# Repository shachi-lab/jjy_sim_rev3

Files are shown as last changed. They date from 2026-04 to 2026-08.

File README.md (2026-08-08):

# 📡 JJY Simulator Rev.3 for ESP32-C3 / ESP8684

Build your own JJY time-signal simulator with an ESP32-C3 or ESP8684!  
This compact simulator reproduces the 40 kHz / 60 kHz JJY radio time signal using PWM output,  
based on accurate time obtained from NTP.  
Rev.3 is developed with ESP-IDF.  

Latest version: **R3-1.0.6**

👉 [README 日本語版はこちら](README_ja.md)

---

## 🪛 Features

* Supports both **ESP32-C3** and **ESP8684**
* Full-featured implementation based on **ESP-IDF**
* **Easy AP mode** for Wi-Fi setup with a single button
* **OLED display** for checking the current time and sync status
* Automatic time synchronization via **NTP**
* Switchable **JJY 40 kHz (eastern Japan) / 60 kHz (western Japan)**
* Output **band optimization** can be selected with an on-board switch
* Signal is radiated from a built-in **simple antenna** on the board
* **H-bridge output stage** for higher output power (may transmit farther than expected)
* Configuration page accessible from a **web browser**
* Supports **time zones** and **DST (Daylight Saving Time)**
* **Hourly Mode** for periodic JJY signal output
* **Night Mode** for reducing OLED display brightness at night
* **Offset Time** adjustment for fine-tuning the transmitted time
* Displays a **clock screen** during operation

<a href="./images/jjy-sim-r3.jpg">
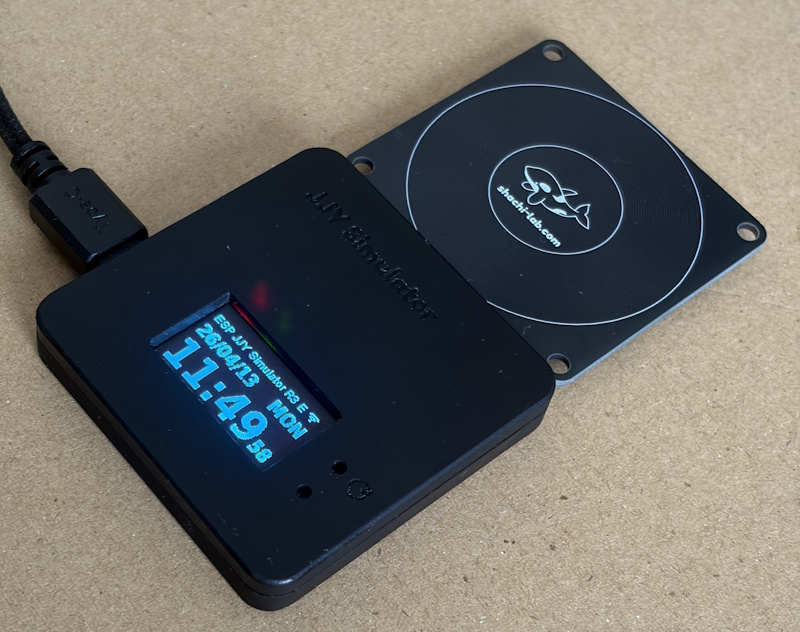
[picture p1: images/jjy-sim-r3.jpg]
JJY Simulator Rev.3
</a><br/>

---

## 🛠 Build and Flash (ESP-IDF / CLI)

JJY-SIM R3 is built and flashed using ESP-IDF.  
R2 was Arduino-based,  
but R3 has moved to ESP-IDF for better timing accuracy and a cleaner overall architecture.

> ### ⚠️ Note
> * This project cannot be built in the Arduino environment
> * This is an ESP-IDF-only project

### ■ Environment

* ESP-IDF v5.x
* Python (with a working `idf.py` environment)

For ESP-IDF setup, please refer to the official documentation.

### ■ Build

Move to the project directory and run:

```bash
idf.py build
```

### ■ Flash

```bash
idf.py flash
```

If you need to specify the serial port:

```bash
idf.py -p COMx flash
```

### ■ Serial Monitor

```bash
idf.py monitor
```

### ■ Full Command

```bash
idf.py -p COMx flash monitor
```

This single command lets you flash the firmware and open the log output at the same time.

### ■ Target Selection

Set the target once during initial setup.
The required target depends on which module you are using.

* When using **ESP32-C3**:

```bash
idf.py set-target esp32c3
```

* When using **ESP8684**:
  Since the ESP8684 is based on **ESP32-C2**,
  select `esp32c2` as the chip target.

```bash
idf.py set-target esp32c2
```

---

## 🛠 Build and Flash (VSCode / GUI)

You can also develop this project using **VSCode + the ESP-IDF Extension**.

### ■ Recommended Extension

* ESP-IDF Extension (Espressif)

By installing the extension in VSCode, you can perform the following from the GUI:

* Build
* Flash
* Serial monitor

### ■ Setup

Set up your environment according to the ESP-IDF Extension instructions.

Once the extension is installed, you can run actions such as:

* `Build`
* `Flash`
* `Monitor`

with a single click.

### ■ Workspace

When opening the project in VSCode,
open **`jjy-sim-r3.code-workspace`** in the source-code folder
to work with the ESP-IDF Extension settings already included.

---

## ⚙️ Usage

### ■ Wi-Fi Setup

* After power-on or reset, press the **CONFIG** switch within 5 seconds  
  On first boot, the device enters Wi-Fi setup mode automatically
* An AP named `JJY-SIM-R3-XXXXXXXX` will start
* Connect from a smartphone or PC → a captive portal will appear
* Select the SSID and enter the password
* You can also configure the band, local time, and DST (Daylight Saving Time) as needed
* Click **[Save and Reboot]** to save the settings and restart the device

### ■ Operation Check

* After power-on or reset, the logo is shown. If left untouched for 5 seconds, the device will try to connect to the configured Wi-Fi AP
* Once connected, it obtains the current time from an NTP server
* The current time is shown on the OLED, and JJY signal output starts from second 0 using PWM
* Just press the **receive button** on your radio-controlled clock and place it nearby

### ■ Controls During Operation

While the clock screen is displayed, the following operations are available:

* Press the **[CONFIG]** button for about 1 second to show the information screen  
  Press **[CONFIG]** again to return to the clock screen
* Press and hold the **[CONFIG]** button for 5 seconds or longer to stop JJY transmission output  
  Press and hold **[CONFIG]** again for 5 seconds or longer to resume JJY transmission output

---

## 🔌 Pin Assignment (Main Signals)

| Function | GPIO | Notes |
| --- | ---- | --- |
| JJY PWM output | 10,4 | Modulated output signals, inverted A/B pair for the H-bridge |
| CONFIG switch  | 9 | Used for Wi-Fi setup (**shared with BOOT pin**) |
| ACT LED | 5 | Activity LED |
| IND LED | 0 | Status indicator LED (can be shared) |
| OLED Reset | 2 | OLED module reset |
| OLED SDA | 7 | OLED I2C data |
| OLED SCL | 6 | OLED I2C clock |

---

## 🧾 File Structure

### 💻 Firmware

* The firmware source code is located in the **`firmware/idf`** folder.
* This firmware uses a rebuilt library, ported as an IDF component, based on the Arduino OLED driver library used in R2.  
This component is publicly available on GitHub.  
👉 [SSD1306 OLED display driver](https://github.com/Shachi-lab/oled_display)
* `storage_key.h` contains placeholder values and can be used as-is.  
  For better security, you may want to replace them with your own values before building.

### 🧰 Hardware

* The hardware design files are located in the **`hardware`** folder.
* The schematic and PCB design data are in **`hardware/KiCad`**.

  * Compatible with **KiCad Ver.9** only (cannot be opened with Ver.8 or earlier)
  * **Gerber data** is included in **`KiCad/PLOT`**, so the board can be fabricated as-is
* The 3D case data is in **`hardware/case_3d`**.

---

## 📸 Appearance / Assembly Examples

These are the board and case exterior views.  
The design uses a black PCB and a black case so that only the display appears to float visually.

<a href="./images/jjy-sim-r3_pcb.jpg">
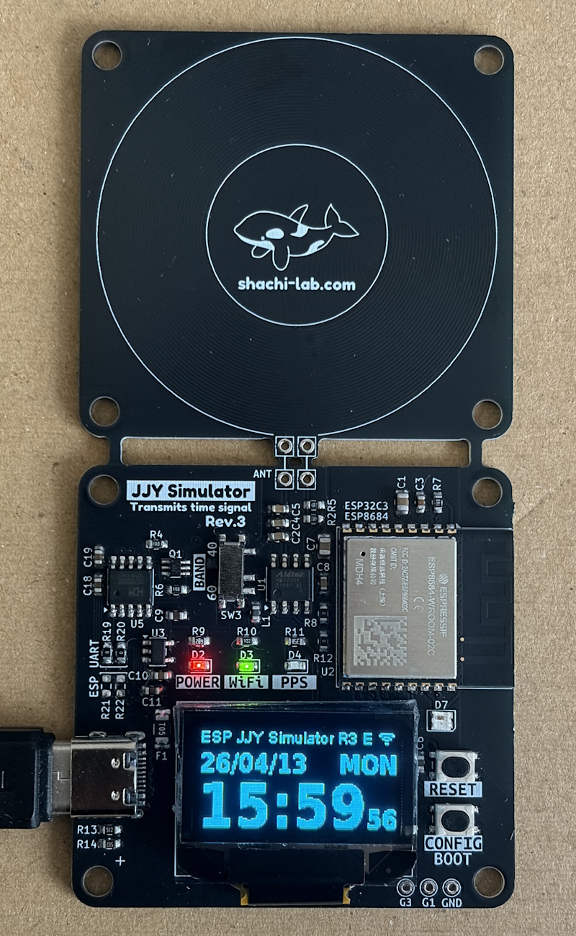
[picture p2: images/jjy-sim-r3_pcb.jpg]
JJY Simulator Rev.3 PCB
</a>
<a href="./images/jjy-sim-r3_case.jpg">
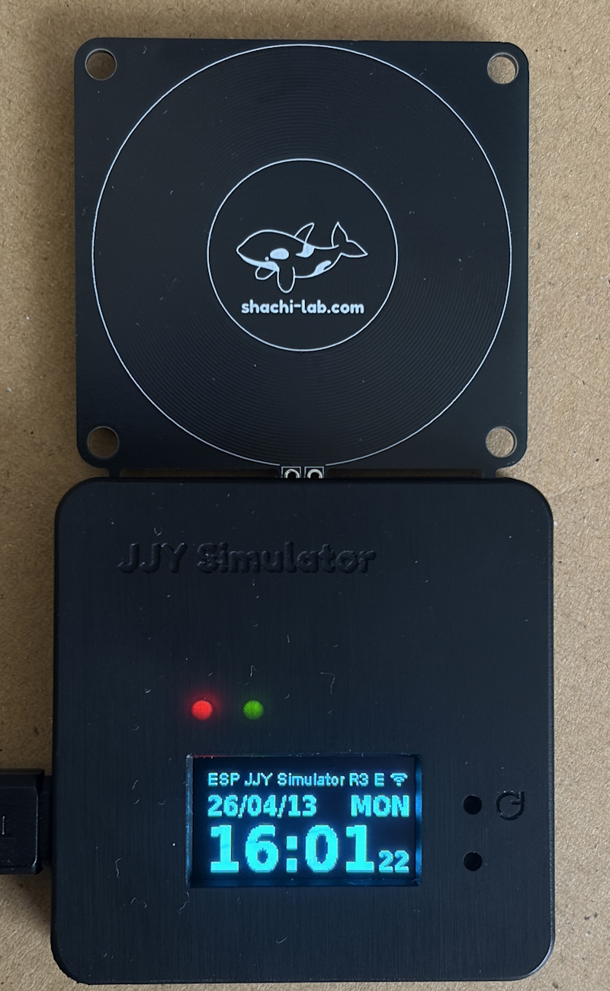
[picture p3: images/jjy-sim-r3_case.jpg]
JJY Simulator Rev.3 with case
</a><br/>

---

## ⚠️ Caution

This device may radiate farther than expected.  
Please make sure to comply with applicable radio regulations when experimenting with it.

---

## 🔗 Support / Documentation  

For the latest information, setup guide, and detailed usage notes, please see the support page.  
👉 [JJY-SIM Support Page](https://blog.shachi-lab.com/support/)  
>Note: The support page is currently available in Japanese only.

---
## 📝 Attribution

JJY-SIM is released under the MIT License.  
You are free to use, modify, and build upon this project.  

When selling, distributing, or publicly releasing something based on JJY-SIM, please include attribution to **Shachi-lab / JJY-SIM** somewhere visible, such as the product page, documentation, README, package, or other accompanying materials.

Example:

* Designed by Shachi-lab
* Based on JJY-SIM by Shachi-lab
* Inspired by JJY-SIM by Shachi-lab

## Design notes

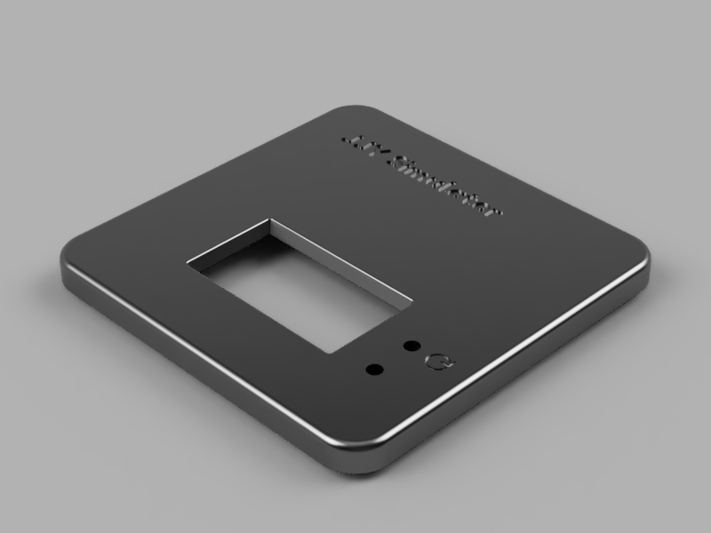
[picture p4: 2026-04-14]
hardware/case_3d/JJY_SIM_R3_Top.png

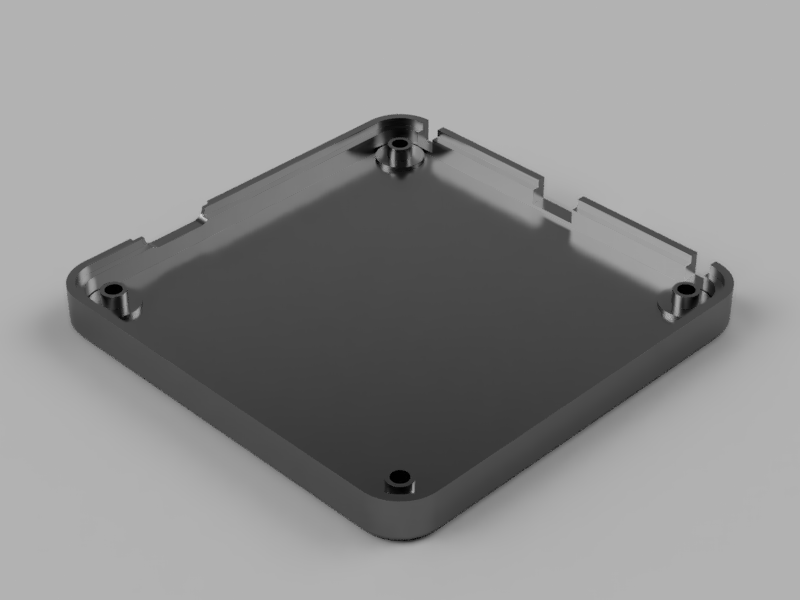
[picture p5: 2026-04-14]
hardware/case_3d/JJY_SIM_R3_Bottom.png

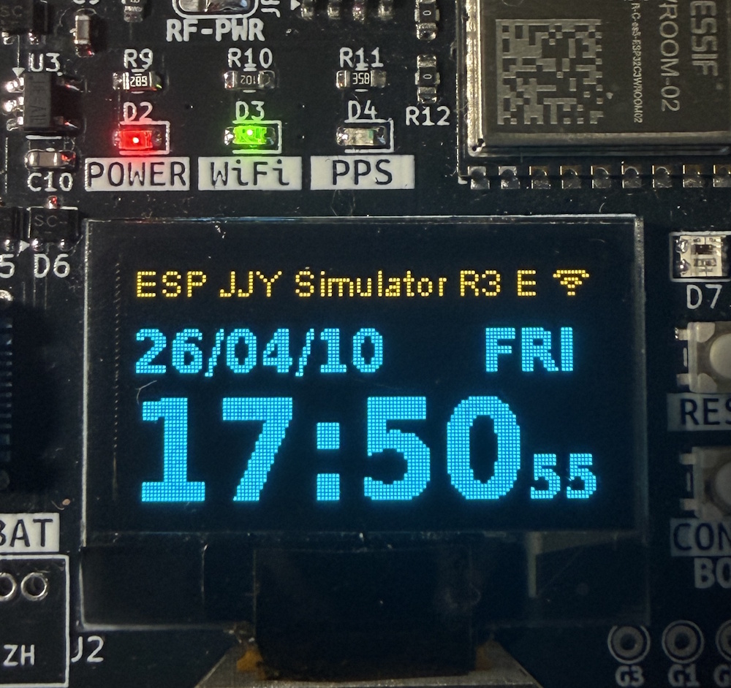
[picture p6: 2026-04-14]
images/jjy-sim-r3_display.jpg

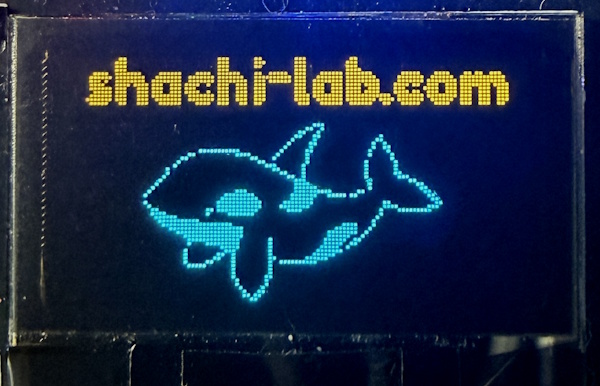
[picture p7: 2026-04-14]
images/oled_display_screen_1.jpg

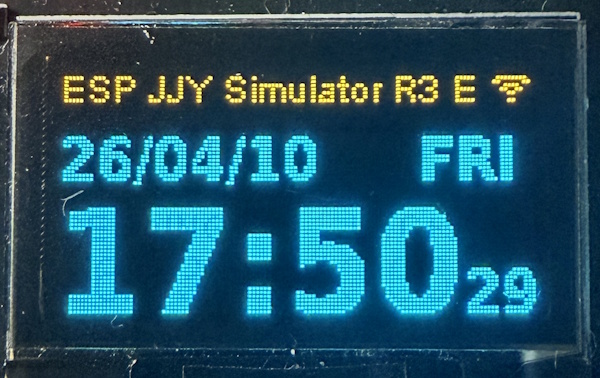
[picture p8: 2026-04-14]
images/oled_display_screen_2.jpg

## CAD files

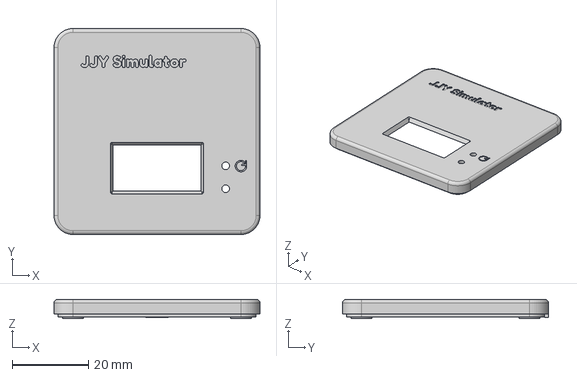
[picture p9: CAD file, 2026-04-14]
hardware/case_3d/JJY_SIM_R3_Top.step
54.0 x 54.0 x 5.10 mm

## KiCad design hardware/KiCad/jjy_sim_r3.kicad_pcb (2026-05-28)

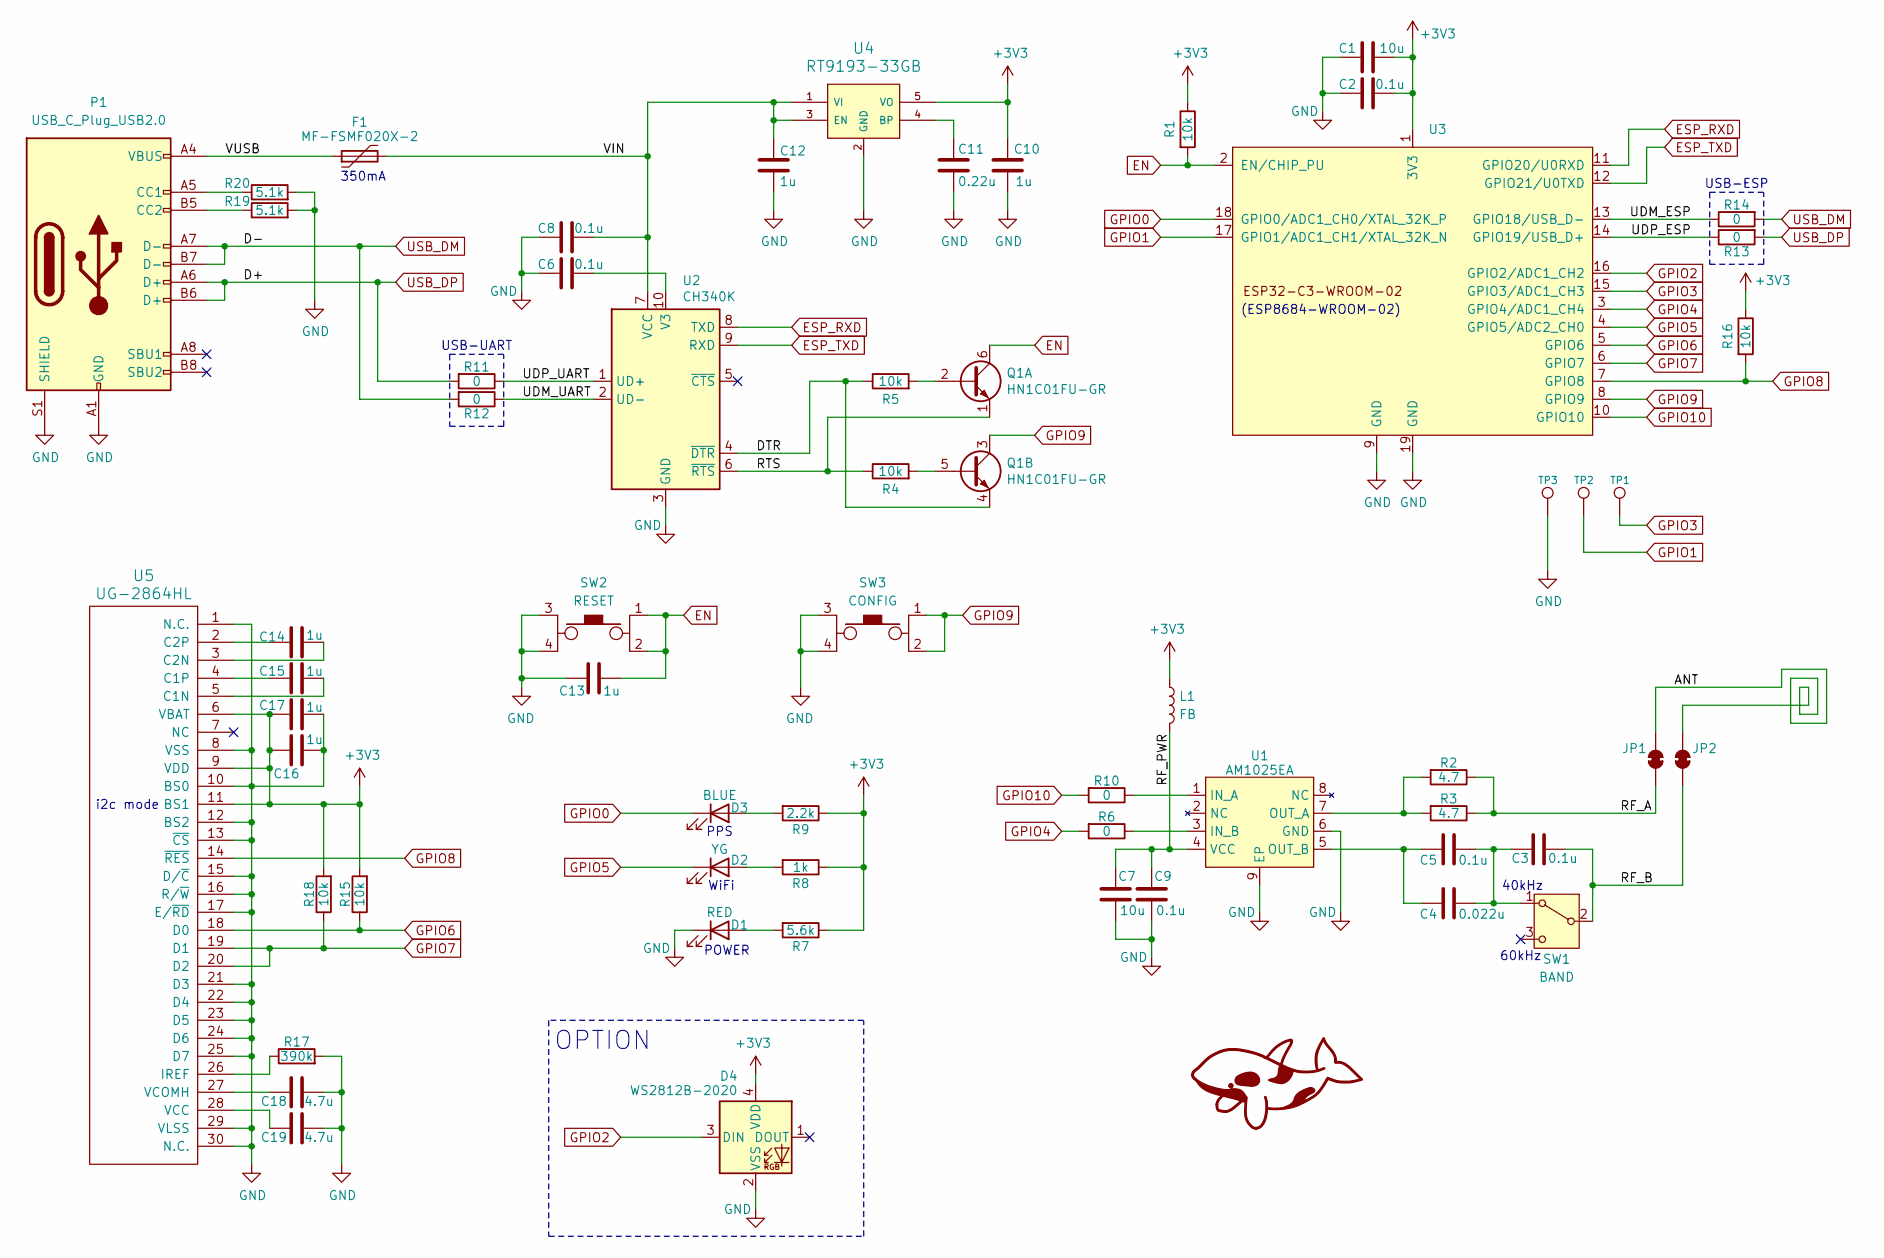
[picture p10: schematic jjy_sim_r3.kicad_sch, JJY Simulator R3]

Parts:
C1, C7: 10u; C_0805_2012Metric
C2, C3, C5, C6, C8, C9: 0.1u; C_0603_1608Metric
C4: 0.022u; C_0603_1608Metric
C10, C12, C13, C14, C15, C16, C17: 1u; C_0603_1608Metric
C11: 0.22u; C_0603_1608Metric
C18, C19: 4.7u; C_0603_1608Metric
D1: RED; LED_0603_1608Metric
D2: YG; LED_0603_1608Metric
D3: BLUE; LED_0603_1608Metric
D4: WS2812B-2020; LED_WS2812B-2020_PLCC4_2.0x2.0mm
F1: MF-FSMF020X-2; Fuse_1206_3216Metric_Pad1.42x1.75mm_HandSolder
JP1: ANT-A; Jumper-2_TH_3.81mm
JP2: GND; Jumper-2_TH_3.81mm
L1: FB; L_0603_1608Metric
P1: USB_C_Plug_USB2.0; 5077CR-16SMC2-BK-TR_Ext
Q1: HN1C01FU-GR; 2-2J1A
R1, R4, R5, R15, R16, R18: 10k; R_0603_1608Metric
R2, R3: 4.7; R_0603_1608Metric
R6, R10, R11, R12, R13, R14: 0; R_0603_1608Metric
R7: 5.6k; R_0603_1608Metric
R8: 1k; R_0603_1608Metric
R9: 2.2k; R_0603_1608Metric
R17: 390k; R_0603_1608Metric
R19, R20: 5.1k; R_0603_1608Metric
SW1: BAND; MSK-12C02
SW2: RESET; SKRPACE010
SW3: CONFIG; SKRPACE010
TP1, TP2, TP3: TP; TestPoint_THTPad_D1.5mm_Drill0.7mm
U1: AM1025EA; eSOP-8_3.9x5.05mm_EP_3.1x2.2mm_P1.27mm
U2: CH340K; SSOP-10-1EP_3.9x4.9mm_P1mm_EP2.1x3.3mm
U3: ESP32-C3-WROOM-02; ESP32-C3-WROOM-02,ESP8684-WROOM-2C
U4: RT9193-33GB; SOT-23-5
U5: UG-2864HL; UG-2864-FPC (Reverse)

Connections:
+3V3: C1.2, C2.2, C10.1, C16.1, C17.1, D4.4 (VDD), L1.1, R1.1, R7.1, R8.1, R9.1, R15.2, R16.1, R18.2, U3.1 (3V3), U4.5 (VO), U5.6 (VBAT), U5.9 (VDD), U5.11 (BS1)
/ANT: JP1.2 (B), JP2.2 (B)
/DTR: Q1.4 (E2), R5.1, U2.4 (~DTR)
/RF_A: JP1.1 (A), R2.1, R3.1
/RF_B: C3.2, JP2.1 (A), SW1.2 (B)
/RF_PWR: C7.1, C9.1, L1.2, U1.4 (VCC)
/RTS: Q1.1 (E1), R4.1, U2.6 (~RTS)
/UDM_ESP: R14.1, U3.13 (GPIO18/USB_D-)
/UDM_UART: R12.1, U2.2 (UD-)
/UDP_ESP: R13.1, U3.14 (GPIO19/USB_D+)
/UDP_UART: R11.1, U2.1 (UD+)
/VIN: C8.2, C12.1, F1.2, U2.7 (VCC), U4.1 (VI), U4.3 (EN)
/VUSB: F1.1, P1.A4 (VBUS), P1.A9 (VBUS), P1.B4 (VBUS), P1.B9 (VBUS)
EN: C13.2, Q1.6 (C1), R1.2, SW2.1, SW2.2, U3.2 (EN/CHIP_PU)
ESP_RXD: U2.8 (TXD), U3.11 (GPIO20/U0RXD)
ESP_TXD: U2.9 (RXD), U3.12 (GPIO21/U0TXD)
GND: C1.1, C2.1, C6.1, C7.2, C8.1, C9.2, C10.2, C11.2, C12.2, C13.1, C16.2, C17.2, C18.2, C19.2, D1.1 (K), D4.2 (VSS), P1.A1 (GND), P1.A12 (GND), P1.B1 (GND), P1.B12 (GND), P1.S1 (SHIELD), R17.2, R19.2, R20.2, SW2.3, SW2.4, SW3.3, SW3.4, TP3.1 (1_1), U1.6 (GND), U1.9 (EP), U2.3 (GND), U2.11 (GND), U3.9 (GND), U3.19 (GND), U4.2 (GND), U5.1 (NC(GND)), U5.8 (VSS), U5.10 (BS0), U5.12 (BS2), U5.13 (~CS), U5.15 (D/~C), U5.16 (R/~W), U5.17 (E/~RD), U5.21 (D3), U5.22 (D4), U5.23 (D5), U5.24 (D6), U5.25 (D7), U5.29 (VLSS), U5.30 (NC(GND))
GPIO0: D3.1 (K), U3.18 (GPIO0/ADC1_CH0/XTAL_32K_P)
GPIO1: TP2.1 (1_1), U3.17 (GPIO1/ADC1_CH1/XTAL_32K_N)
GPIO2: D4.3 (DIN), U3.16 (GPIO2/ADC1_CH2)
GPIO3: TP1.1 (1_1), U3.15 (GPIO3/ADC1_CH3)
GPIO4: R6.2, U3.3 (GPIO4/ADC1_CH4)
GPIO5: D2.1 (K), U3.4 (GPIO5/ADC2_CH0)
GPIO6: R15.1, U3.5 (GPIO6), U5.18 (D0)
GPIO7: R18.1, U3.6 (GPIO7), U5.19 (D1), U5.20 (D2)
GPIO8: R16.2, U3.7 (GPIO8), U5.14 (~RES)
GPIO9: Q1.3 (C2), SW3.1, SW3.2, U3.8 (GPIO9)
GPIO10: R10.2, U3.10 (GPIO10)
unnamed: D1.2 (A), R7.2
unnamed: D2.2 (A), R8.2
unnamed: D3.2 (A), R9.2
unnamed: P1.A5 (CC1), R20.1
unnamed: P1.B5 (CC2), R19.1
unnamed: Q1.2 (B1), R5.2
unnamed: Q1.5 (B2), R4.2
unnamed: C3.1, C4.2, C5.2, SW1.1 (A)
unnamed: R10.1, U1.1 (IN_A)
unnamed: R6.1, U1.3 (IN_B)
unnamed: R2.2, R3.2, U1.7 (OUT_A)
unnamed: C4.1, C5.1, U1.5 (OUT_B)
unnamed: C11.1, U4.4 (BP)
unnamed: C15.2, U5.5 (C1N)
unnamed: C15.1, U5.4 (C1P)
unnamed: C14.2, U5.3 (C2N)
unnamed: C14.1, U5.2 (C2P)
unnamed: R17.1, U5.26 (IREF)
unnamed: C19.1, U5.28 (VCC)
unnamed: C18.1, U5.27 (VCOMH)
unnamed: C6.2, U2.10 (V3)
USB_DM: P1.A7 (D-), P1.B7 (D-), R12.2, R14.2
USB_DP: P1.A6 (D+), P1.B6 (D+), R11.2, R13.2

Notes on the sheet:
USB-UART
PPS
OPTION
350mA
i2c mode
60kHz
USB-ESP
WiFi
40kHz
POWER
(ESP8684-WROOM-02)

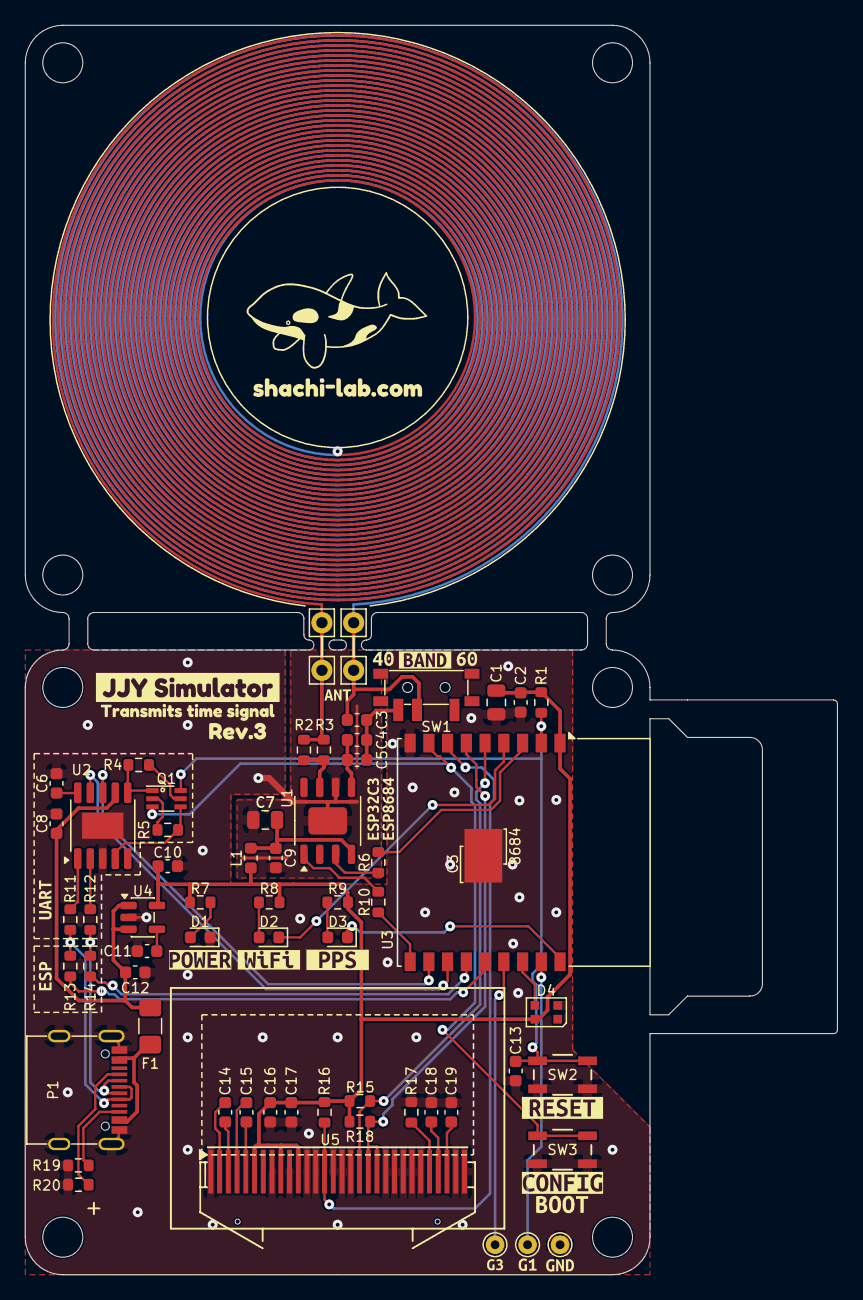
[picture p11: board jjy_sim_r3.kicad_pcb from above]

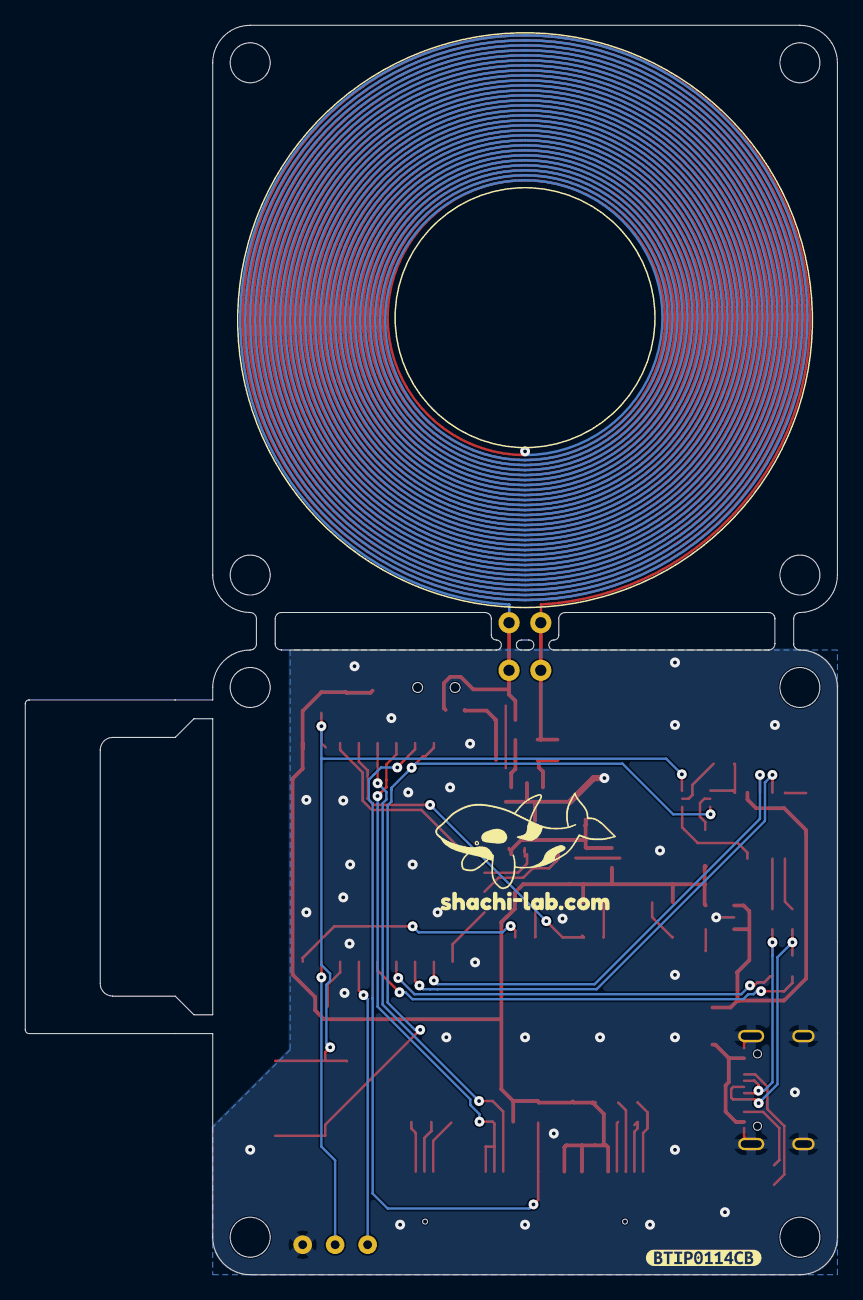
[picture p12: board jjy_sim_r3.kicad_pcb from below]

Board: 2 copper layers, 65.0 x 100.0 mm, 90 parts (2 on the bottom side), 51 nets.

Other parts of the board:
1, 2, 3, 4, 5, 6, 7, 8: (no value)
kibuzzard-1, kibuzzard-28: G***; kibuzzard-68D2B4BB
kibuzzard-2: G***; kibuzzard-6982098F
kibuzzard-3: G***; kibuzzard-69820977
kibuzzard-4: G***; kibuzzard-69820ADF
kibuzzard-5: G***; kibuzzard-68D3A9C1
kibuzzard-6: G***; kibuzzard-6646C6AC
kibuzzard-6A179A92: G***; kibuzzard-6A179A92
kibuzzard-7: G***; kibuzzard-68D3A910
kibuzzard-8: G***; kibuzzard-69816480
kibuzzard-9: G***; kibuzzard-69867CAB
kibuzzard-10: G***; kibuzzard-698209E3
kibuzzard-11: G***; kibuzzard-669B6BC9
kibuzzard-12: G***; kibuzzard-669B6DC4
kibuzzard-13: G***; kibuzzard-68E061D7
kibuzzard-14: G***; kibuzzard-69965DBC
kibuzzard-15: G***; kibuzzard-665B3587
kibuzzard-16: G***; kibuzzard-665B357F
kibuzzard-17: G***; kibuzzard-669B16B9
kibuzzard-18: G***; kibuzzard-665A8DD6
kibuzzard-19: G***; kibuzzard-669B4532
kibuzzard-20: G***; kibuzzard-665B35AE

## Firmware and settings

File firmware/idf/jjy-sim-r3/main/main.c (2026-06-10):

/*
 * JJY-SIM R3
 *
 * JJY signal simulator using ESP32 / ESP8684.
 *
 * - Generates 40kHz / 60kHz JJY signal
 * - Synchronizes time via NTP over Wi-Fi
 * - Provides OLED display for status and time
 *
 * Copyright (c) 2026 Shachi-lab
 * SPDX-License-Identifier: MIT
 *
 * Developed by Shachi-lab
 * https://shachi-lab.com
 *   ____  _                _     _     _       _
 *  / ___)| |__   __ _  ___| |__ |_|   | | __ _| |__
 *  \___ \| '_ \ / _` |/ __) '_ \ _  _ | |/ _` | '_ \
 *   ___) | | | | (_| | (__| | | | ||_|| | (_| | |_) |
 *  (____/|_| |_|\__,_|\___)_| |_|_|   |_|\__,_|_.__/
 */
#include <stdio.h>
#include <string.h>
#include <stdlib.h>
#include <stdbool.h>
#include <stdint.h>
#include <errno.h>
#include <math.h>
#include <time.h>

#include "freertos/FreeRTOS.h"
#include "freertos/task.h"
#include "freertos/event_groups.h"

#include "esp_system.h"
#include "esp_event.h"
#include "esp_log.h"
#include "esp_wifi.h"
#include "esp_netif.h"
#include "esp_mac.h"
#include "nvs.h"
#include "nvs_flash.h"
#include "esp_sntp.h"
#include "driver/i2c_master.h"
#include "esp_app_desc.h"

#include "jjy-sim-r3.h"
#include "jjy_pwm.h"
#include "led.h"
#include "settings.h"
#include "wifi_mng.h"

#include "OLEDDisplay.h"
#include "resource/shachi-lab_logo.h"
#include "resource/icon_image.h"
#include "resource/DejaVu_Sans_Condensed_Bold_16.h"
#include "resource/DejaVu_Sans_Condensed_Bold_38.h"

static const char *TAG __attribute__((unused)) = "main";

static char JJY_char = JJY_CHAR_EAST;     // JJY signal character
static char tz_str[10] = {0};              // timezone string
static int config_wait_remain;            // configuration remain
static char *config_str = "";             // configuration string
static char time_str[40];                 // time string
static struct tm *timeinfo = NULL;        // current time
static bool jjy_enable = true;            // JJY signal enable
static int ntp_retry_count = 0;           // NTP retry count
static char *ntp_server = NTP_URL;        // NTP server
static char offset_str[8] = {0};          // offset string

typedef enum {
  DISP_REBOOT      = -3,
  DISP_CONFIG_MODE = -2,
  DISP_WAIT_CONFIG = -1,
  DISP_INIT_LOGO   = 0,
  DISP_VERSION     = 1,
  DISP_CONNECTING  = 2,
  DISP_CONNECTED   = 3,
  DISP_NTP_SYNCING = 4,
  DISP_SENDING     = 5
} disp_screen_t;

static void disp_screen(disp_screen_t mode);

// SNTPを使って時刻を同期する
static bool wait_for_time_sync(int timeout_ms)
{
  static bool is_initialized = false;

  if (is_initialized == false ) {
    is_initialized = true;
    ESP_LOGI(TAG, "Starting SNTP");

    // SNTP設定
    esp_sntp_setoperatingmode(SNTP_OPMODE_POLL);
    esp_sntp_setservername(0, ntp_server);
    esp_sntp_init();
  }

  int retry = 0;
  int max_retry = timeout_ms > 0 ? timeout_ms / 500 : 0;

  while (max_retry == 0 || retry < max_retry) {

    timeinfo = jjy_get_time();

    // 年が2020未満なら未同期とみなす
    if (timeinfo->tm_year >= 20) {
      sntp_set_sync_mode(SNTP_SYNC_MODE_SMOOTH);
      ESP_LOGI(TAG, "Time synchronized");
      ESP_LOGI(TAG, "Current time: %04d-%02d-%02d %02d:%02d:%02d",
                timeinfo->tm_year + 1900,
                timeinfo->tm_mon + 1,
                timeinfo->tm_mday,
                timeinfo->tm_hour,
                timeinfo->tm_min,
                timeinfo->tm_sec);
      return true;
    }
    vTaskDelay(pdMS_TO_TICKS(500));
    retry++;
  }
  ESP_LOGW(TAG, "SNTP sync timeout");
  return false;
}

// 時刻同期待ち
static bool main_wait_for_config(void)
{
  gpio_config_t io_conf = {
    .pin_bit_mask = (1ULL << PIN_CONFIG),
    .mode = GPIO_MODE_INPUT,
    .pull_up_en = GPIO_PULLUP_ENABLE,
    .pull_down_en = GPIO_PULLDOWN_DISABLE,
    .intr_type = GPIO_INTR_DISABLE
  };
  gpio_config(&io_conf);

  for (int i = CONFIG_WAIT_TIME; i > 0; i -= CONFIG_WAIT_TICK) {
    config_wait_remain = (i + 500)/ 1000;
    disp_screen(DISP_WAIT_CONFIG);
    vTaskDelay(pdMS_TO_TICKS(CONFIG_WAIT_TICK));
    if (gpio_get_level(PIN_CONFIG) == 0) {
      return true;
    }
  }
  return false;
}

// Wi-Fi接続状態に応じたアイコンを返して、LEDを制御
static const uint8_t *get_wifi_icon_led(wifi_status_t status, bool ntp_flag)
{ 
  static const uint8_t *icon = NULL;

  switch (status) {
  case WIFI_STATUS_DISCONNECTED :
    icon = wifi_12x12_off_bits;
    led_blink(PIN_LED_WIFI, LED_MODE_BLINK_SLOW);
    break;
  case WIFI_STATUS_CONNECTED :
    icon = wifi_12x12_on_bits;
    led_blink(PIN_LED_WIFI, ntp_flag ? LED_MODE_BLINK_FAST : LED_MODE_ON);
    break;
  case WIFI_STATUS_CONNECTING :
    icon = (icon == wifi_12x12_conn1_bits) ? wifi_12x12_conn2_bits : wifi_12x12_conn1_bits;
    led_blink(PIN_LED_WIFI, LED_MODE_BLINK_SLOW);
    break;
  default :
    icon = NULL;
    led_blink(PIN_LED_WIFI, LED_MODE_OFF);
    break;
  }
  return icon;
}

// I2CベースのOLEDの初期化
static i2c_master_bus_handle_t i2c_bus_init(void)
{
  i2c_master_bus_config_t bus_cfg = {
    .clk_source = I2C_CLK_SRC_DEFAULT,
    .i2c_port = I2C_NUM_0,
    .sda_io_num = PIN_OLED_SDA,
    .scl_io_num = PIN_OLED_SCL,
    .glitch_ignore_cnt = 7,
    .flags.enable_internal_pullup = true,
  };
  i2c_master_bus_handle_t i2c_bus;
  esp_err_t ret = i2c_new_master_bus(&bus_cfg, &i2c_bus);
  if (ret != ESP_OK) {
    return NULL;
  }
  return i2c_bus;
}

static const uint8_t brightness_table[11] = {
  0,    // 0: ほぼ消灯に近い（でも見える）
  1,    // 1 
  5,    // 2
  15,   // 3
  25,   // 4
  45,   // 5
  75,   // 6
  110,  // 7
  150,  // 8
  200,  // 9
  255   // 10: 最大
};

void disp_brightness(int hour)
{
  static int brightness_save = -1;
  int brightness;

  if ((hour >= 0) && s_settings.night_mode && (hour >= NIGHT_TIME_START || hour < NIGHT_TIME_END)) {
    brightness = NIGHT_TIME_BRIGHTNESS;
  } else {
    brightness = s_settings.brightness;
  }
  if (brightness < 0 || brightness > sizeof(brightness_table)-1) {
      brightness = sizeof(brightness_table) - 1;
  }
  if (brightness != brightness_save) {
    brightness_save = brightness;
    OLEDDisplay_setBrightness(brightness_table[brightness]);
  }
}

static void disp_fade(bool direction)
{
  for (uint8_t i = 0; i < sizeof(brightness_table); i++) {
    uint8_t idx = direction ? sizeof(brightness_table) - 1 - i : i;
    OLEDDisplay_setBrightness(brightness_table[idx]);
    vTaskDelay(pdMS_TO_TICKS(50));
  }
}

// OLEDの画面描画
static void disp_screen(disp_screen_t mode)
{ 
  char buff_str[40];
  static i2c_master_bus_handle_t i2c_bus = NULL;
  int brightness_hour = -1;

  if (i2c_bus == NULL) {
    i2c_bus = i2c_bus_init();
    if (i2c_bus == NULL) return;

    oled_config_t oled_cfg = OLED_CONFIG_DEFAULT();
    oled_cfg.i2c.bus = i2c_bus;
    oled_cfg.rst_pin = PIN_OLED_RST;
    OLEDDisplay_config(&oled_cfg);
    OLEDDisplay_init();
    OLEDDisplay_flipScreenVertically();
  }

  if (mode == DISP_INIT_LOGO) {
    OLEDDisplay_drawBuffer(shachilab_logo_bits, sizeof(shachilab_logo_bits));
    OLEDDisplay_display();
    return;
  }

  OLEDDisplay_clear();
  OLEDDisplay_setFont(ArialMT_Plain_10);

  OLEDDisplay_drawString( 0,  0, JJYSIM_PRODUCT_NAME );
  buff_str[2] = '\0'; 
  buff_str[1] = jjy_enable ? '\0' : 'X'; 
  buff_str[0] = JJY_char;
  OLEDDisplay_drawString( 99,  0, buff_str );
  if (s_settings.hourly_mode) {
    buff_str[1] = 'H';
    OLEDDisplay_drawString( 86,  0, buff_str + 1 );
  }

  const uint8_t *icon = get_wifi_icon_led(wifi_get_status(), mode == DISP_NTP_SYNCING); 
  if (icon)  OLEDDisplay_drawXbm(116, 2, 12, 12, icon);

  do {
    if (mode == DISP_VERSION || mode <= DISP_WAIT_CONFIG) {
      const esp_app_desc_t *app = esp_app_get_description();
      OLEDDisplay_drawStringf( 0, 14, buff_str, "Version %s - " JJYSIM_CHIP_FAMILY, (char*)app->version );
    
      if (mode == DISP_VERSION) {
        OLEDDisplay_drawString( 0, 30, JJYSIM_COPYRIGHT );
        OLEDDisplay_drawString( 0, 42, JJYSIM_VENDOR_NAME );
      } else
      if (mode == DISP_WAIT_CONFIG) {
        OLEDDisplay_drawString( 0, 30, "Waiting for CONFIG" );
        OLEDDisplay_drawStringf(0, 42, buff_str, "%d sec left", config_wait_remain );
      } else
      if (mode == DISP_CONFIG_MODE) {  
        OLEDDisplay_drawString( 0, 30, config_str );
        OLEDDisplay_drawString( 0, 42, "Enter to CONFIG mode" );
      } else
      if (mode == DISP_REBOOT) {
        OLEDDisplay_drawString( 0, 42, "Reboot now!!" );
      }
      break;
    }
    if (mode < DISP_CONNECTING) break;

    if (mode == DISP_SENDING) {

      brightness_hour = timeinfo->tm_hour;

      if (s_settings.disp_mode == 0) {
        if (timeinfo == NULL) break;
        if (s_settings.dst) {
          OLEDDisplay_drawString(108, 35, "DST");
        }
        time_str[10] = '\0';
        time_str[16] = '\0';
        OLEDDisplay_setFont((uint8_t*)DejaVu_Sans_Condensed_Bold_16);
        OLEDDisplay_drawString(  0, 14, time_str+ 2);
        OLEDDisplay_drawString(109, 49, time_str+17);
        jjy_get_week_str(buff_str);
        OLEDDisplay_setTextAlignment(TEXT_ALIGN_CENTER);
        OLEDDisplay_drawString(110, 14, buff_str+ 0);
        OLEDDisplay_setTextAlignment(TEXT_ALIGN_LEFT);

        OLEDDisplay_setFont((uint8_t*)DejaVu_Sans_Condensed_Bold_38);
        if (time_str[11] == '0') {
          OLEDDisplay_drawString( 23, 28, time_str+12);
        } else {
          OLEDDisplay_drawString( -1, 28, time_str+11);
        }
        break;
      }
    }

    OLEDDisplay_drawStringf( 0, 14, buff_str, "SSID : %s", s_settings.ssid );

    if (mode == DISP_CONNECTING) {
      OLEDDisplay_drawString( 0, 24, "Connecting..." );
    } else {
      OLEDDisplay_drawStringf( 0, 24, buff_str, "Connect : %s", get_wifi_addr_str() );
      if (mode == DISP_NTP_SYNCING) {
        OLEDDisplay_drawString( 0, 34, "NTP SYNCING...");
        OLEDDisplay_drawString( 0, 44, ntp_server);
        if (ntp_retry_count > 0) { 
          OLEDDisplay_drawStringf( 0, 54, buff_str, "Retrying : %d", ntp_retry_count );
        }
      } else
      if (mode == DISP_SENDING) {
        OLEDDisplay_drawString( 54, 34, tz_str );
        OLEDDisplay_drawString(110, 34, offset_str );
      if (jjy_enable) {
          OLEDDisplay_drawString( 0, 34, "SEND ON");
        } else {
          OLEDDisplay_drawString( 0, 34, "SEND OFF");
        }
        if (timeinfo == NULL) break;
        OLEDDisplay_setFont(ArialMT_Plain_16);
        OLEDDisplay_drawString( 0, 46, time_str+2);
      }
    }
  } while (0);

  if (mode > DISP_VERSION) {
    disp_brightness(brightness_hour);
  }
  OLEDDisplay_display();
}

static void config_switch_task(const struct tm *tm_now)
{
  static uint32_t call_count = 0;
  static bool prev_pressed = false;
  static int press_count = 0;
  static bool long_press_done = false;
  static bool manual_jjy = false;

  call_count++;

  bool pressed = (gpio_get_level(PIN_CONFIG) == 0);

  if (pressed && !prev_pressed) {
    s_settings.disp_mode = !s_settings.disp_mode;
    press_count = 1;
    long_press_done = false;
  } else
  if (pressed && prev_pressed) {
    press_count++;

    if (!long_press_done && press_count >= LONG_PRESS_SEC) {

      jjy_enable = !jjy_enable;
      manual_jjy = true;
      long_press_done = true;
    }
  } else if (!pressed && prev_pressed) {
    press_count = 0;
    long_press_done = false;
  }

  prev_pressed = pressed;

  if (!s_settings.hourly_mode) {
    return;
  }

  if (tm_now->tm_sec != 0) {
    return;
  }

  bool auto_jjy_enable = false;
  int houurly_start = 60 - s_settings.hourly_range;
  int houurly_end = s_settings.hourly_range + 1;

  if (call_count < BOOT_FORCE_ON_COUNT) {
      if (long_press_done) call_count = BOOT_FORCE_ON_COUNT;
      auto_jjy_enable = true;
  } else {
    int min = tm_now->tm_min;
    if (min == houurly_start || min == houurly_end) {
      manual_jjy = false;
    }
    auto_jjy_enable = (min >= houurly_start || min < houurly_end);
  }
  if (manual_jjy == false) {
    jjy_enable = auto_jjy_enable;
  }
}

// main
void app_main(void)
{
  led_init();
  led_blink(PIN_LED_WIFI, LED_MODE_ON);
  led_blink(PIN_LED_PPS , LED_MODE_ON);

  const esp_app_desc_t *app = esp_app_get_description();

  printf("\n%s", JJYSIM_PRODUCT_NAME);
  printf("\n%s", app->version);
  printf("\n%s", JJYSIM_COPYRIGHT " " JJYSIM_VENDOR_NAME "\n");

  disp_screen(DISP_INIT_LOGO);
  disp_fade(false);

  esp_err_t ret = nvs_flash_init();
  if (ret == ESP_ERR_NVS_NO_FREE_PAGES || ret == ESP_ERR_NVS_NEW_VERSION_FOUND) {
    ESP_ERROR_CHECK(nvs_flash_erase());
    ret = nvs_flash_init();
  }
  ESP_ERROR_CHECK(ret);

  load_settings(&s_settings);

  if (s_settings.band == JJY_BAND_WEST) JJY_char = JJY_CHAR_WEST;
  jjy_get_tz_str(tz_str, s_settings.timezone, s_settings.dst);
  if (s_settings.dst) strcat(tz_str, "*");
  sprintf(offset_str, "%+d", s_settings.offset_time);
  if (s_settings.ntp_mode && s_settings.ntp_url[0] != '\0') {    
    ntp_server = s_settings.ntp_url;
  } else {
    ntp_server = NTP_URL;
  }

  vTaskDelay(pdMS_TO_TICKS(2000));
  disp_fade(true);

  led_blink(PIN_LED_WIFI, LED_MODE_OFF);
  led_blink(PIN_LED_PPS , LED_MODE_OFF);

  disp_screen(DISP_VERSION);
  disp_fade(false);
  vTaskDelay(pdMS_TO_TICKS(2000));

  wifi_init_common();

  ESP_LOGI(TAG, "Wi-Fi Valid : %d", s_settings.wifi_valid);
  if (s_settings.wifi_valid) {

    ESP_LOGI(TAG, "Saved Wi-Fi found: %s", s_settings.ssid);
    ESP_LOGI(TAG, "JJY settings: band=%d dst=%d tz=%.2f",
            s_settings.band, s_settings.dst, s_settings.timezone);
  
    led_blink(PIN_LED_PPS , LED_MODE_BLINK_SLOW);
    if (main_wait_for_config() == false) {

      led_blink(PIN_LED_PPS , LED_MODE_OFF);
      wifi_start_sta_only(s_settings.ssid, s_settings.pass);

      for (uint8_t i = 0; i < CONNECT_TIMEOUT; i++) {
        disp_screen(DISP_CONNECTING);
        if (is_wifi_connected()) break;
      }

      if (wifi_get_status() == WIFI_STATUS_CONNECTED) {

        ESP_LOGI(TAG, "Connected to Wi-Fi");

        while (1) {

          disp_screen(DISP_NTP_SYNCING);

          if (wait_for_time_sync(NTP_TIMEOUT*1000)) {
            // 時刻OK
            jjy_pwm_init(s_settings.band, s_settings.dst, s_settings.timezone, s_settings.offset_time);
            while (1) {
              timeinfo = jjw_wait_next_second(time_str);
              config_switch_task(timeinfo);
              jjy_set_signal_enable(jjy_enable);
              jjy_pwm_proc(time_str);
              disp_screen(DISP_SENDING);
            }
          } else {
              ntp_retry_count++;
          }
        }  
      } else { 
        config_str = "WiFi connection timeout.";
      }
    } else {
      config_str = "[CONFIG] was pressed.";
    }
  } else {
    config_str = "SSID is not set.";
  }

  ESP_LOGI(TAG, "%s", config_str);
  ESP_LOGI(TAG, "Enter to CONFIG mode");
  disp_screen(DISP_CONFIG_MODE);
  led_blink(PIN_LED_WIFI, LED_MODE_OFF);
  led_blink(PIN_LED_PPS , LED_MODE_ON);
  enter_setup_mode();

  while (is_reboot_req() == false) vTaskDelay(pdMS_TO_TICKS(1000));

  disp_screen(DISP_REBOOT);
  led_blink(PIN_LED_WIFI, LED_MODE_BLINK_FAST);
  led_blink(PIN_LED_PPS , LED_MODE_BLINK_FAST);

  vTaskDelay(pdMS_TO_TICKS(2000));
  esp_restart();
}

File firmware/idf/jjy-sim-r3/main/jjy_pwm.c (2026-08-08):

/*
 * JJY-SIM R3 - JJY PWM Generator
 *
 * Generates JJY time signal (40kHz / 60kHz) using PWM (H-bridge).
 *
 * - Creates 1-minute JJY frame from system time
 * - Outputs JJY modulation synchronized to second boundary
 * - Uses ESP-IDF LEDC for PWM generation
 * - Uses esp_timer for precise pulse timing
 *
 * Copyright (c) 2026 Shachi-lab
 * SPDX-License-Identifier: MIT
 *
 * Developed by Shachi-lab
 * https://shachi-lab.com
 *   ____  _                _     _     _       _
 *  / ___)| |__   __ _  ___| |__ |_|   | | __ _| |__
 *  \___ \| '_ \ / _` |/ __) '_ \ _  _ | |/ _` | '_ \
 *   ___) | | | | (_| | (__| | | | ||_|| | (_| | |_) |
 *  (____/|_| |_|\__,_|\___)_| |_|_|   |_|\__,_|_.__/
 */
#include <stdio.h>
#include <string.h>
#include <stdlib.h>
#include <stdbool.h>
#include <stdint.h>
#include <errno.h>
#include <math.h>
#include <sys/time.h>
#include <time.h>

#include "freertos/FreeRTOS.h"
#include "freertos/task.h"
#include "freertos/event_groups.h"

#include "esp_err.h"
#include "esp_log.h"
#include "esp_system.h"
#include "esp_timer.h"
#include "driver/ledc.h"

#include "jjy-sim-r3.h"
#include "led.h"
#include "jjy_pwm.h"

static const char *TAG __attribute__((unused)) = "jjy_pwm";

#define JJY_T_BIT0      800000        // 800ms
#define JJY_T_BIT1      500000        // 500ms
#define JJY_T_PM        200000        // 200ms

#define JJY_BIT_ZERO    0
#define JJY_BIT_OFF     -1
#define JJY_BIT_PMn     -2
#define JJY_BIT_M       -3

#define TICK_US         (1000000LL / configTICK_RATE_HZ)

#define PWM_BITS        LEDC_TIMER_8_BIT
#define PWM_CH_A        LEDC_CHANNEL_0
#define PWM_CH_B        LEDC_CHANNEL_1
#define PWM_TIMER       LEDC_TIMER_0
#define PWM_MODE        LEDC_LOW_SPEED_MODE

#define PWM_DUTY_MAX    ((1U << PWM_BITS) - 1)
#define PWM_DUTY_ON     (PWM_DUTY_MAX / 2)     // 必要に応じて調整
#define PWM_DEAD        0                      // 必要に応じて調整

static bool jjy_signal_enable = true;
static struct tm timeinfo;
static int jjy_frame[60];
static esp_timer_handle_t s_jjy_off_timer = NULL;
static bool dst_flag = false;
static int offset = 0;

static void set_timezone(float timezone, int dst);
static void wait_for_next_second(void);
static void create_jjy_frame(struct tm *tm);
static void jjy_put_bit(int flag);
static void send_char_immediately(char c);

static esp_err_t pwm_setup(int freq);
static void pwm_on(void);
static void pwm_off(void);
static void pwm_stop(void);

// Initialize JJY PWM generator
bool jjy_pwm_init(int band, int dst, float timezone, int offset_time)
{
  ESP_LOGI(TAG, "JJY-SIM main start");

  offset = offset_time * 60;
  dst_flag = dst;
  set_timezone(timezone, dst);

  if (pwm_setup(band*1000) != ESP_OK) {
    ESP_LOGE(TAG, "PWM setup failed");   
    return false;
  }
  wait_for_next_second();
  return true;
}

struct tm *jjy_get_time(void)
{
  time_t now;

  time(&now);
  now += offset;
  if (dst_flag) now += 3600;
  localtime_r(&now, &timeinfo);
  timeinfo.tm_year -= 100;

  return &timeinfo;
}

struct tm *jjw_wait_next_second(char *timeNowStr)
{
  wait_for_next_second();
 
  jjy_get_time();

  sprintf(timeNowStr, "20%02d/%02d/%02d,%02d:%02d:%02d",
      timeinfo.tm_year, timeinfo.tm_mon+1, timeinfo.tm_mday, timeinfo.tm_hour, timeinfo.tm_min, timeinfo.tm_sec);

  return &timeinfo;
} 

// Process JJY signal output
void jjy_pwm_proc(char *timeNowStr)
{
  static int current_min = -1;

  if (current_min != timeinfo.tm_min) {

    printf("\n%s : ", &timeNowStr[2]);
    for (int i = 0; i < timeinfo.tm_sec; i++) send_char_immediately(' ');

    create_jjy_frame(&timeinfo);
    current_min = timeinfo.tm_min;
  }
  jjy_put_bit(jjy_frame[timeinfo.tm_sec]);
}

// Set JJY signal enable
void jjy_set_signal_enable(bool enable)
{
  jjy_signal_enable = enable;
}

// Convert day of the week to string
char *jjy_get_week_str(char *buff)
{
  const char *week[] = {"SUN", "MON", "TUE", "WED", "THU", "FRI", "SAT"};
  strcpy(buff, week[timeinfo.tm_wday]);
  return buff;
}

// Convert timezone to TZ string
char *jjy_get_tz_str(char *tz, float timezone, int dst)
{
  if (timezone < -12.0 || timezone > 12.0) timezone = TIMEZONE_JAPAN;

  int hour = (int)timezone;
  int min  = (int)((timezone - hour) * 60 + 0.5);

  sprintf(tz, "UTC%+d:%02d", hour, abs(min));

  return tz;
}

// Set timezone
static void set_timezone(float timezone, int dst)
{
  char tz[32];

  // 符号反転（ここ重要）
  timezone = -timezone;
  jjy_get_tz_str(tz, timezone, dst);

  setenv("TZ", tz, 1);
  tzset();
}

// Wait for next second
static void wait_for_next_second(void)
{
  struct timeval tv;
  int last_sec = -1;
  const suseconds_t tick_us = TICK_US;

  while (1) {
    gettimeofday(&tv, NULL);

    if (last_sec == -1) {
      last_sec = tv.tv_sec;
    }

    // 秒が変わったら終了
    if (tv.tv_sec != last_sec) {
      break;
    }

    // 残り時間で待ち方を変える
    if (tv.tv_usec < tick_us) {
      // まだ余裕ある → 寝る
      vTaskDelay(1);
    } else {
      // 秒境界直前 → 詰める
      taskYIELD();
    }
  }
}

/*
 * intをBCDに変換
 */
static int get_int_to_bcd(int n)
{
  int res = n % 10;
  res += ((n/ 10)%10)<<4;
  res += ((n/100)%10)<<8;
  return res;
}

/*
 * 偶数パリティを計算
 */
static int get_even_parity(int n)
{
  n ^= n >> 8;
  n ^= n >> 4;
  n ^= n >> 2;
  n ^= n >> 1;
  return n & 1;
}
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

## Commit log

2026-04-14 1st commit
    First public release
    [JJY_SIM_R3_Top.step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]
2026-04-25 Add Night mode Add Hourly mode Bug fix Refine behavior
    [jjy-sim-r3.h, jjy_pwm.c, led.c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]
2026-05-28 Update project for KiCad 10.0 and add local libraries
    - Updated KiCad project files for KiCad 10.0
    - Moved the BAND-SW position
    - Added project-local KiCad libraries
    - Included custom libraries that were previously not committed
    [jjy_sim_r3-B_Cu.gbl, jjy_sim_r3-B_Mask.gbs, jjy_sim_r3-B_Paste.gbp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]
2026-08-08 R3-1.0.6 Fixed a bug affecting 60 kHz output.
    [jjy_pwm.c]
